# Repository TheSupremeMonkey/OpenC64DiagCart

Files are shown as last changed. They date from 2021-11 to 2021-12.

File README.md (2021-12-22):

# UNTESTED PLEASE DON'T USE THE GERBERS YET!

# OpenC64DiagCart
OpenC64DiagCart started as a fork of OpenC64Cart by SukkoPera [available at](https://github.com/SukkoPera/OpenC64Cart). The primary goal being to replace all the jumpers with a single rotary DIP switch while also retaining the ability to have one of the 8 image slots be used as a C64 Dead Test. 
 
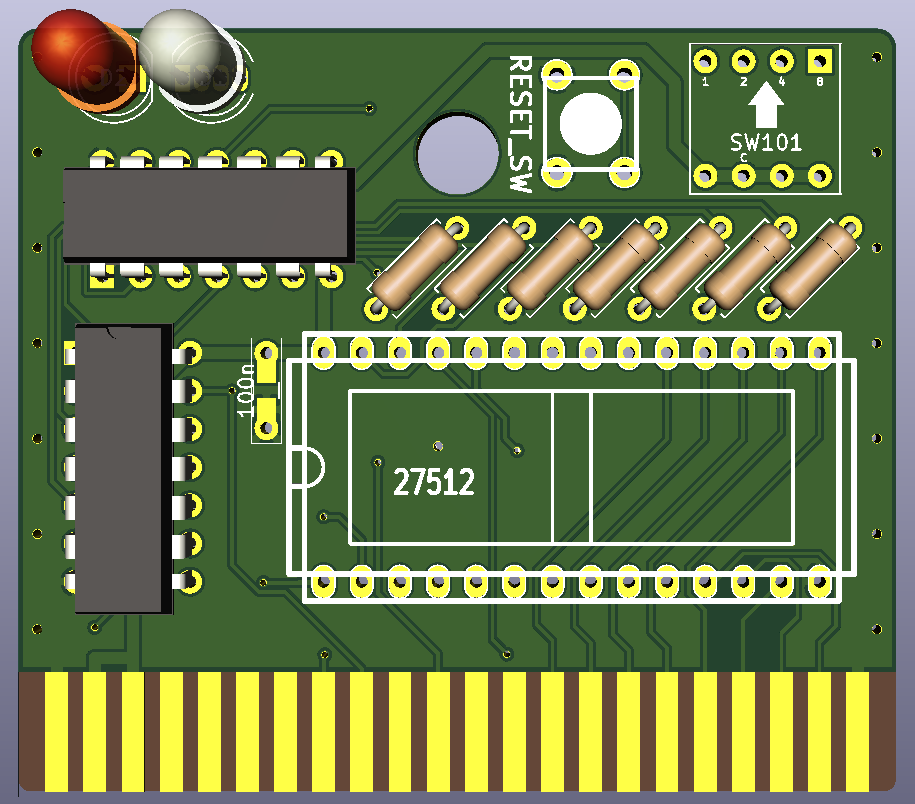
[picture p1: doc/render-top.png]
Board

 
### Summary
Most Commodore 64 diagnostic cartriges are a standard 8k image, the exception being the dead that has to be run in Ultimax mode. To keep the design simple and make it easy to prototype, I decided to use parts I already had. In the end I ended up using a 74LS02 quad 2-input NOR gate and a 4066 quad bilateral switch, which are both spare parts I keep around for reparing Commdoe 64 motherboards. The 74LS02 is used to read the state of the DIP switch which is tied to the last 3 address pins (A13,A14, & A15) of the 27512. When all 3 pins are low the CE and OE pins on the 27512 are connected through a switch in 4066 to ROMH and GAME is set high. For any other combination of A13, A14, and A15 CE and OE are connected through a different switch on the 4066 to ROML and EXROM is set high. This means that the first image out of 8 on the 27512 ROM will automatically be in Ultimax mode and can run a dead test. All the other images can be any 8k cartridge image you want. 
 
 I also added an RGB LED to give a visual queue as to which image is selected. THe RGB is also tied to the dip switch so that meant that when all three addresses are low the LED will be off. I added a 2nd LED that is triggered when Utilimax mode is on, this way the dead test always gets a special light. 
 
### Configuration

|Slot	|Image								|RGB	|LED	|A13 (B)	|A14 (G)	|A15 (R)	|MODE|
|---|---|---|---|---|---|---|----|
|0		|Dead Test Rev 781220				|OFF	|ON		|0			|0			|0			|Dead Test|
|1		|C-64 Diagnostic Rev 586220*		|Blue	|OFF	|1			|0			|0			|Normal|
|2		|Roßmöller Doctor64					|Green	|OFF	|0			|1			|0			|Normal|
|3		|Trilogic 64 Doctor					|Cyan	|OFF	|1			|1			|0			|Normal|
|4		|C64 Burn In “Final Rev 3.0”		|Red	|OFF	|0			|0			|1			|Normal|
|5		|1541 Diagnostic					|Purple	|OFF	|1			|0			|1			|Normal|
|6		|PSID64 Sid Player					|Yellow	|OFF	|0			|1			|1			|Normal|
|7		|C-64 Diagnostic Rev 586220-SWINSID	|White	|OFF	|1			|1			|1			|Normal|

### Thanks
While this is technically a fork of [OpenC64Cart](https://github.com/SukkoPera/OpenC64Cart), it was also very helpful to look at the design of Bwack's [Vers64Cart](https://github.com/bwack/Versa64Cart). A ton of credit also needs to go to the [World Of Jani](http://blog.worldofjani.com/) blog for both the [diagnostic images](http://blog.worldofjani.com/?p=164) and [code](http://blog.worldofjani.com/?p=1981), as well a ton of [documentation](http://blog.worldofjani.com/?p=879) on how these cartridges work.

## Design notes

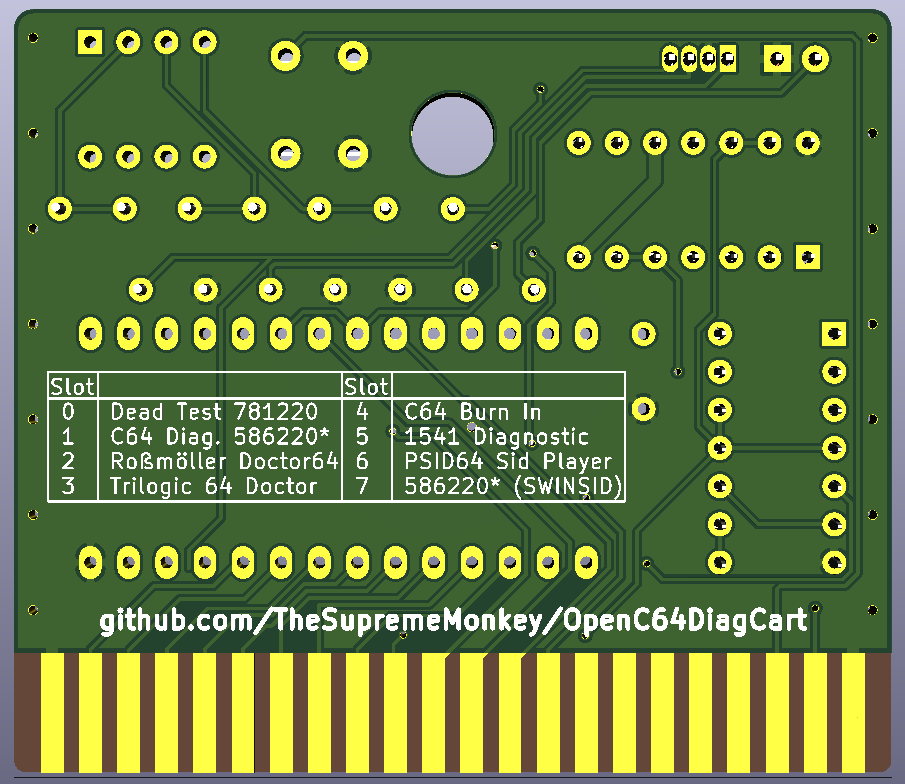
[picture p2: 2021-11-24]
doc/render-bottom.png

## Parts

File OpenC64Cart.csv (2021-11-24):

Id | Designator | Package | Quantity | Designation | Supplier and ref
1 | U102 | DIP-14_W7.62mm | 1 | 4066
2 | R7,R1 | R_Axial_DIN0207_L6.3mm_D2.5mm_P7.62mm_Horizontal | 2 | 200
3 | D2 | LED_D5.0mm | 1 | LED
4 | D1 | LED_D5.0mm-4_RGB | 1 | LED_RCGB
5 | R3,R2 | R_Axial_DIN0207_L6.3mm_D2.5mm_P7.62mm_Horizontal | 2 | 150
6 | J99 | C64_PEG_HOLE | 1 | PEG_HOLE
7 | U101 | DIP-14_W7.62mm | 1 | 74LS02
8 | SW101 | SW_DIP_SPSTx04_Slide_9.78x12.34mm_W7.62mm_P2.54mm | 1 | SW_DIP_x04
9 | R6,R5,R4 | R_Axial_DIN0207_L6.3mm_D2.5mm_P7.62mm_Horizontal | 3 | 1k
10 | U2 | dil_28-600_socket | 1 | 27512
11 | C1 | C_0805+THT | 1 | 100n
12 | SW1 | PCB_PUSH | 1 | RESET_SW
13 | U1 | C64-Cart | 1 | C64-Exp-Port

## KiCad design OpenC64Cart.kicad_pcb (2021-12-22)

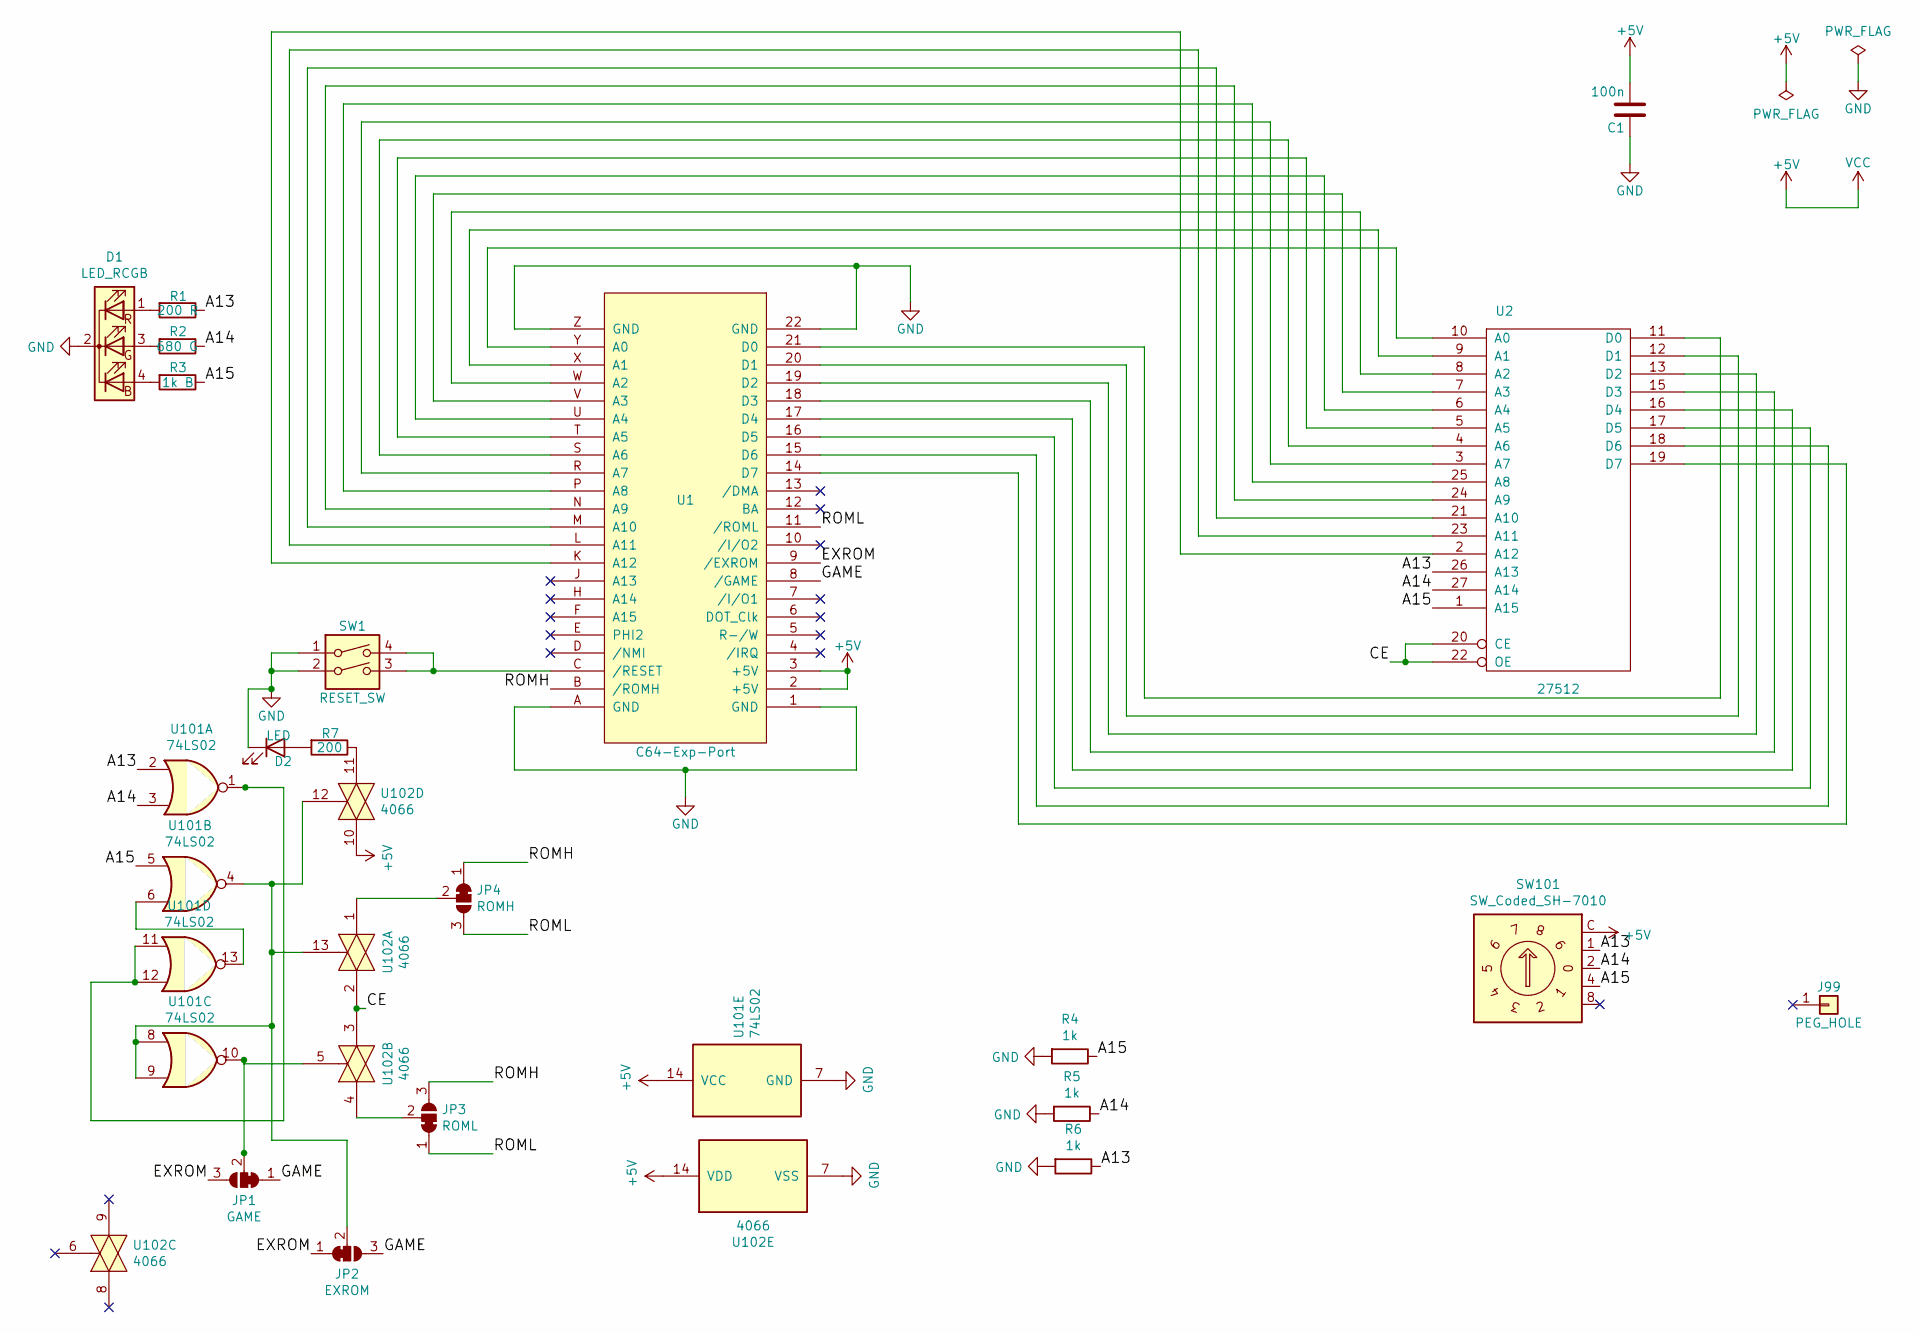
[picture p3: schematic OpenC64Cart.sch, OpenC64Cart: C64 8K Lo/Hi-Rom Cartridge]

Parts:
C1: 100n; C_0805+THT
D1: LED_RCGB; LED_D5.0mm-4_RGB
D2: LED; LED_D5.0mm
J99: PEG_HOLE; C64_PEG_HOLE
JP1: GAME; SolderJumper-3_P1.3mm_Bridged12_RoundedPad1.0x1.5mm_NumberL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
JP2: EXROM; SolderJumper-3_P1.3mm_Bridged12_RoundedPad1.0x1.5mm_NumberL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
JP3: ROML; SolderJumper-3_P1.3mm_Bridged12_RoundedPad1.0x1.5mm_NumberL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
JP4: ROMH; SolderJumper-3_P1.3mm_Bridged12_RoundedPad1.0x1.5mm_NumberL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
R1: 200 R; R_Axial_DIN0207_L6.3mm_D2.5mm_P7.62mm_Horizontal
R2: 680 G; R_Axial_DIN0207_L6.3mm_D2.5mm_P7.62mm_Horizontal
R3: 1k B; R_Axial_DIN0207_L6.3mm_D2.5mm_P7.62mm_Horizontal
R4, R5, R6: 1k; R_Axial_DIN0207_L6.3mm_D2.5mm_P7.62mm_Horizontal
R7: 200; R_Axial_DIN0207_L6.3mm_D2.5mm_P7.62mm_Horizontal
SW1: RESET_SW; PCB_PUSH
SW101: SW_Coded_SH-7010; SW_DIP4-ROTARY-BCD-8or10
U1: C64-Exp-Port; C64-Cart
U2: 27512; dil_28-600_socket
U101: 74LS02; DIP-14_W7.62mm
U102: 4066; DIP-14_W7.62mm

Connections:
+5V: C1.2, SW101.C, U1.2 (+5V), U1.3 (+5V), U2.28 (VCC), U101.14 (VCC), U102.10, U102.14 (VDD)
/A13: R1.1, R6.1, SW101.1, U2.26 (A13), U101.2
/A14: R2.1, R5.1, SW101.2, U2.27 (A14), U101.3
/A15: R3.1, R4.1, SW101.4, U2.1 (A15), U101.5
/CE: U2.20 (CE), U2.22 (OE), U102.2, U102.3
/EXROM: JP1.3 (B), JP2.1 (A), U1.9 (/EXROM)
/GAME: JP1.1 (A), JP2.3 (B), U1.8 (/GAME)
/ROMH: JP3.3 (B), JP4.1 (A), U1.B (/ROMH)
/ROML: JP3.1 (A), JP4.3 (B), U1.11 (/ROML)
GND: C1.1, D1.2 (K), D2.1 (K), R4.2, R5.2, R6.2, SW1.1, SW1.2, U1.1 (GND), U1.22 (GND), U1.A (GND), U1.Z (GND), U2.14 (GND), U101.7 (GND), U102.7 (VSS)
unnamed: D1.1 (RA), R1.2
unnamed: D1.3 (GA), R2.2
unnamed: D1.4 (BA), R3.2
unnamed: D2.2 (A), R7.2
unnamed: JP1.2 (C), U101.10, U102.5
unnamed: JP2.2 (C), U101.4, U101.8, U101.9, U102.12, U102.13
unnamed: JP3.2 (C), U102.4
unnamed: JP4.2 (C), U102.1
unnamed: R7.1, U102.11
unnamed: SW1.3, SW1.4, U1.C (/RESET)
unnamed: U1.14 (D7), U2.19 (D7)
unnamed: U1.15 (D6), U2.18 (D6)
unnamed: U1.16 (D5), U2.17 (D5)
unnamed: U1.17 (D4), U2.16 (D4)
unnamed: U1.18 (D3), U2.15 (D3)
unnamed: U1.19 (D2), U2.13 (D2)
unnamed: U1.20 (D1), U2.12 (D1)
unnamed: U1.21 (D0), U2.11 (D0)
unnamed: U1.K (A12), U2.2 (A12)
unnamed: U1.L (A11), U2.23 (A11)
unnamed: U1.M (A10), U2.21 (A10)
unnamed: U1.N (A9), U2.24 (A9)
unnamed: U1.P (A8), U2.25 (A8)
unnamed: U1.R (A7), U2.3 (A7)
unnamed: U1.S (A6), U2.4 (A6)
unnamed: U1.T (A5), U2.5 (A5)
unnamed: U1.U (A4), U2.6 (A4)
unnamed: U1.V (A3), U2.7 (A3)
unnamed: U1.W (A2), U2.8 (A2)
unnamed: U1.X (A1), U2.9 (A1)
unnamed: U1.Y (A0), U2.10 (A0)
unnamed: U101.1, U101.11, U101.12
unnamed: U101.6, U101.13

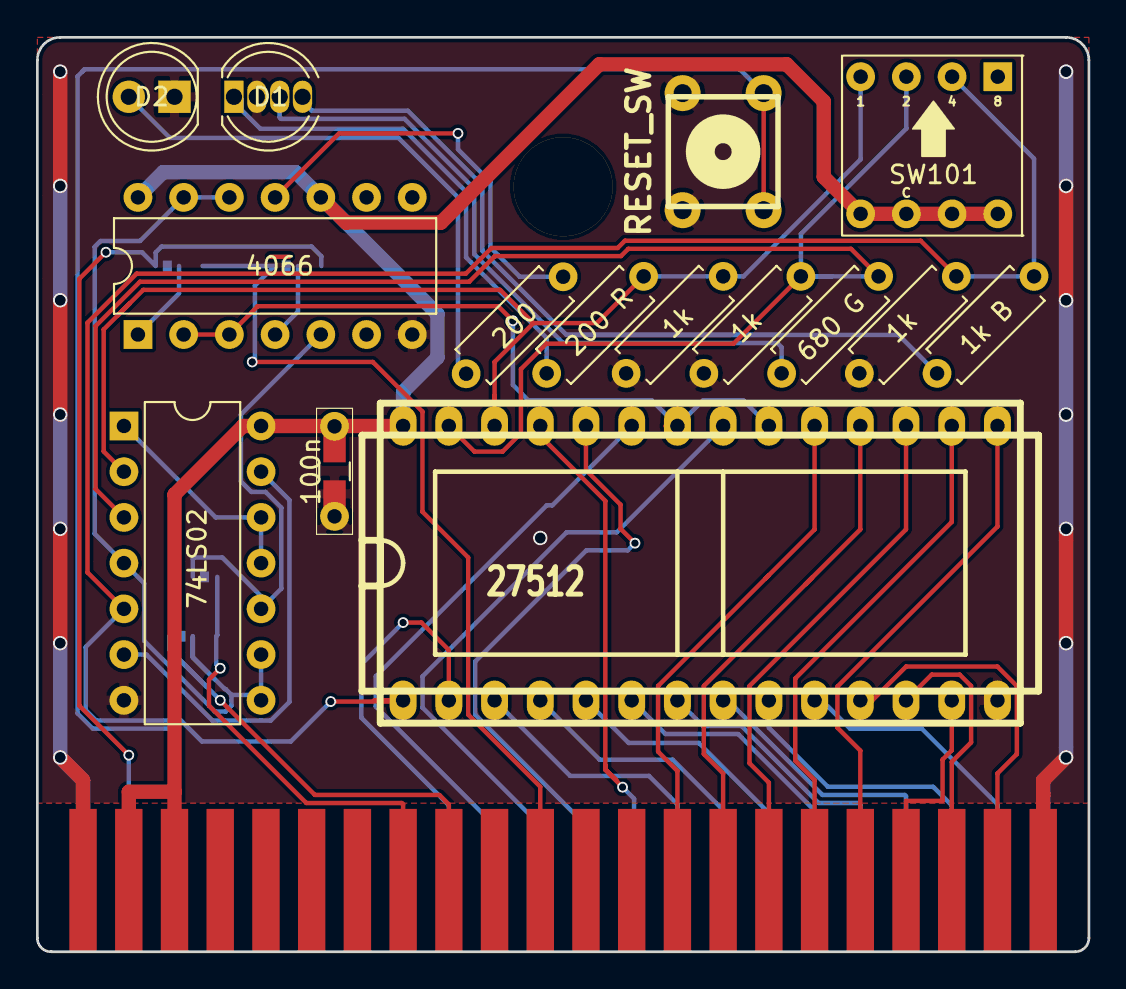
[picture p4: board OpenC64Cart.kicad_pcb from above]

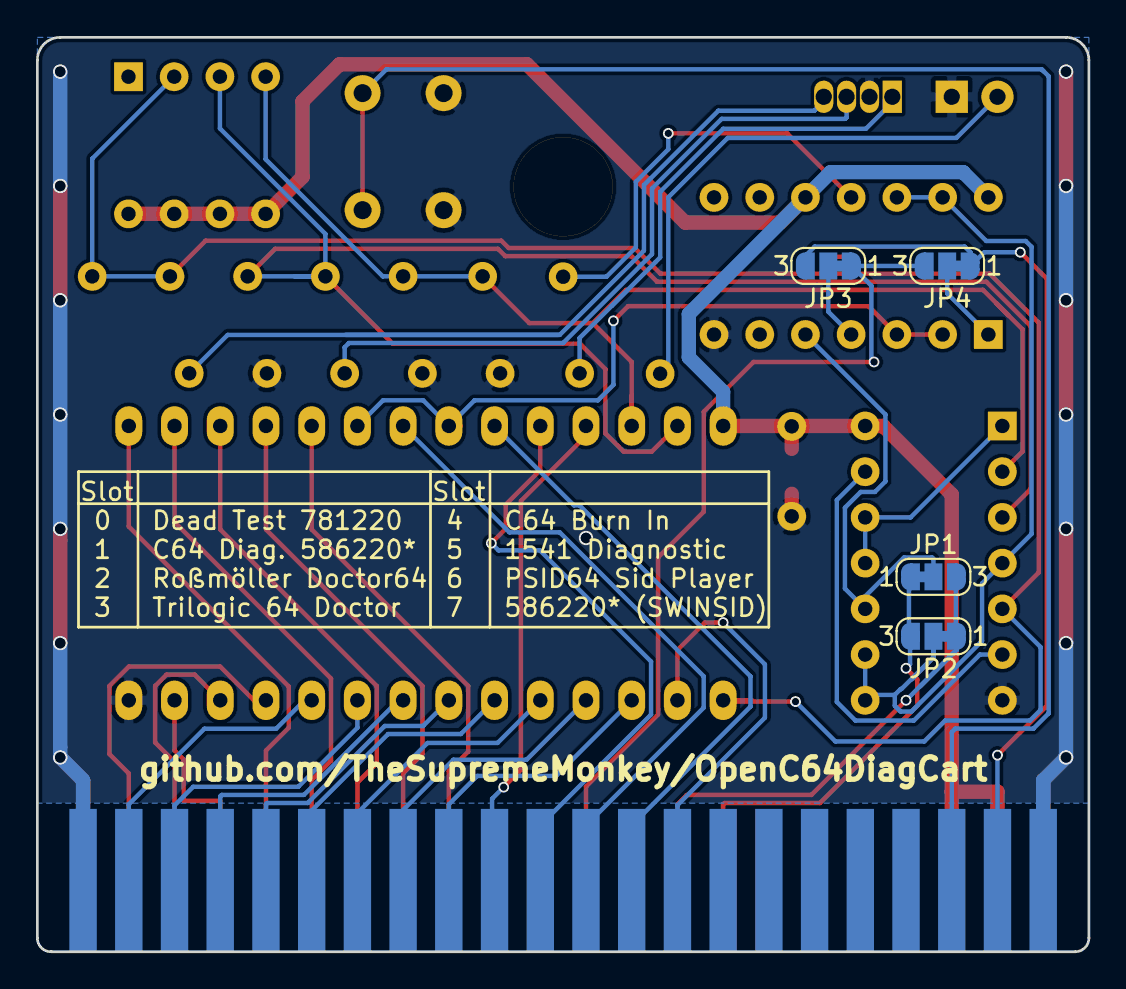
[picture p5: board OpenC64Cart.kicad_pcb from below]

Board: 2 copper layers, 58.4 x 50.8 mm, 21 parts (4 on the bottom side), 43 nets.

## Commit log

2021-11-24 OpenC64DiagCart
    Initial commit of OpenC64DiagCart fork.
    [OpenC64Cart-2021-11-13-16-00-54.sch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]
2021-11-24 PCB Render Update
2021-12-15 Fixed Everything
    This is still untested beta. I had a bunch of things wrong on my first test PCBs.
    [OpenC64Cart.kicad_pcb, OpenC64Cart.sch]
2021-12-22 Tested
    Finally received the latest revision PCB and everything is now working. I tweaked the LED resistors for the RGB LEDs I have but they may need tweaked depending on the actual specs of the LED used.
    [OpenC64Cart-B_Cu.gbl, OpenC64Cart-B_Mask.gbs, OpenC64Cart-B_SilkS.gbo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]
